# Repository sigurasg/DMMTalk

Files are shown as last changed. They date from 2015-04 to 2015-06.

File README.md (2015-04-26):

# DMMTalk

A battery-powered appendix to UNI-T 61E that speaks the settings and readings.

# TODO

* Add photodiode and amplifier for serial reception.
* Add button.
* Add volume control.
  * These two might take the form of a quadrature encoder with a button.
* Add headphone jack.
* Find a suitable SPI FLASH ROM.
  * Maybe [AT45DB081E
](http://www.adestotech.com/wp-content/uploads/DS-45DB081E_028.pdf)
  * Create a library component for same.
* Wire MSP430G2553 up.
  * RST/TEST go to RTS/CTS through resistors to allow BSL.
  * Need to find out how FT230 behaves without power, hopefully its outputs are
    3-state.
  * Even if it's tri-state, it'll conduct through the ESD protection diode, so
    this requires a switch to isolate the powered-down serial chip from
    the reset pin, as well as the TEST pin, to make sure in-circuit programming
    through the two-wire protocol works. Maybe something like
    http://www.onsemi.com/pub_link/Collateral/NL7WB66-D.PDF.
  * UCA0 or UCB0 drives the SPI bus.
  * One pin controls the analog power switch.
* Find suitable rail-to-rail op-amps.
  * Need 1.8V operating voltage at the bottom.
  * Need reasonable output current drive capability.
  * Maybe a bridge-drive headphone or speaker amp is better?

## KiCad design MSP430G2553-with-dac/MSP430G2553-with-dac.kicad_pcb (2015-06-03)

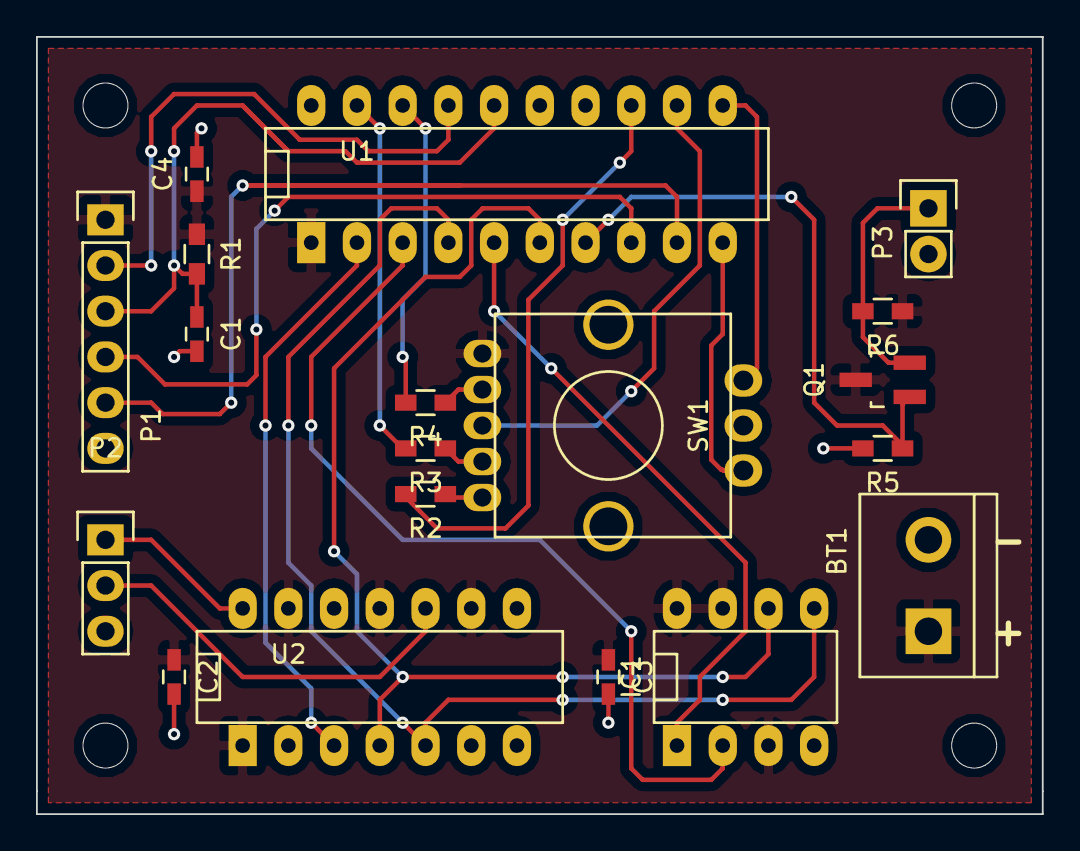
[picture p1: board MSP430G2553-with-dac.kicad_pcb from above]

Board: 2 copper layers, 55.9 x 43.2 mm, 19 parts (0 on the bottom side), 24 nets.

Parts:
BT1: Battery; bornier2
C1: 1n; C_0603_HandSoldering
C2, C3, C4: 100n; C_0603_HandSoldering
IC1: MX25L4006E; DIP-8__300_ELL
P1: DEBUG; Pin_Header_Straight_1x06
P2: OUT; Pin_Header_Straight_1x03
P3: PHOTODIODE; Pin_Header_Straight_1x02
Q1: 2N3906; SOT-23_Handsoldering
R1: 47K; R_0603_HandSoldering
R2, R3, R4: 220; R_0603_HandSoldering
R5, R6: 100K; R_0603_HandSoldering
SW1: PEL12T
U1: MSP430G2553IN20; DIP-20__300_ELL
U2: MCP4922-E/P; DIP-14__300_ELL

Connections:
/A_OUT: P2.1, U2.14
/BLED: R4.2, U1.18
/BUTTON: SW1.3, U1.12
/B_OUT: P2.2, U2.10
/DACCS#: U1.2, U2.3
/FLASHCS#: IC1.1, U1.5
/GLED: R3.2, U1.19
/PH_IN: Q1.1, R5.1, U1.7
/Q_A: SW1.8, U1.10
/Q_B: SW1.6, U1.11
/RLED: R2.2, U1.13
/RST#: C1.1, P1.3, R1.2, U1.16
/RXD: P1.4, U1.8
/SCK: IC1.6, U1.6, U2.4
/SDI: IC1.5, U1.4, U2.5
/SDO: IC1.2, U1.3
/TEST: P1.2, U1.17
/TXD: P1.5, U1.9
GND: BT1.2, C1.2, C2.2, C3.2, C4.2, IC1.4, P1.6, P2.3, P3.2, R5.2, SW1.7, U1.20, U2.8, U2.12
unnamed: P3.1, Q1.2, R6.2
unnamed: R2.1, SW1.1
unnamed: R3.1, SW1.2
unnamed: R4.1, SW1.4
VCC: BT1.1, C2.1, C3.1, C4.1, IC1.3, IC1.7, IC1.8, P1.1, Q1.3, R1.1, R6.1, SW1.5, U1.1, U2.1, U2.9, U2.11, U2.13

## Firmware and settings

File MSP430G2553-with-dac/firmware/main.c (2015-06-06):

/*
 * main.c
 *
 *  Created on: Jun 2, 2015
 *      Author: siggi
 */

#include <msp430.h>
#include <isr_compat.h>
#include <stdint.h>

#include "timer.h"

#define nullptr 0

// Hardware pins.
#define Q_A BIT2
#define Q_B BIT3
#define BUTTON BIT4

// The LEDs are inverted, pull down to turn LEDs on.
#define RLED BIT5
#define GLED BIT6
#define BLED BIT7
#define LEDMASK (RLED | GLED | BLED)

void InitClock() {
  // 16MHz DCO for main clock.
  BCSCTL1 = CALBC1_16MHZ;
  DCOCTL = CALDCO_16MHZ;
}

void InitTimer0() {
  // Set timer0 up for regular interrupts.
  TA0CTL = TASSEL_2 |  // Use SMCLK.
	   ID_0 |  // Divide by 1.
	   MC_2 |  // Continuous mode.
	   TAIE;  // Enable overflow interrupts.
}

void InitLEDPort() {
  P2SEL	&= ~LEDMASK;
  P2DIR |= LEDMASK;
  P2OUT |= LEDMASK;
}

void InitButtons() {
  // Button and quadrature switches are inputs.
  P2DIR &= ~(Q_A | Q_B | BUTTON);
  // Enable pulldown resistor for the button, and pullups
  // for the quadrature switches.
  P2REN |= (Q_A | Q_B | BUTTON);
  P2OUT &= ~BUTTON;
  P2OUT |= Q_A | Q_B;

  // Set up for interrupt on button low->high transition.
  // The button is N/O, connected to VCC with a pulldown.
  P2IES &= ~BUTTON;

  // And for quadrature changes.
  P2IES = (P2IES & ~(Q_A | Q_B)) | (P2IN & (Q_A | Q_B));

  // Enable the port interrupts.
  P2IE |= (Q_A | Q_B | BUTTON);
}

typedef struct RGB {
  uint8_t intens;
  uint8_t r, g, b;
} RGB;

RGB led = { 128, 127, 127, 127 };
uint8_t mode = 0;

static void PWMLEDs(struct Timer* t);
struct LEDTimerSchedule {
  // The current state 0-3.
  uint8_t state;
  // Mask of the LEDs that are on at any stage, ends in a zero mask.
  uint8_t masks[4];
  // The delay to the next state.
  uint32_t delays[4];
};
struct LEDTimerSchedule led_schedule;
struct LEDTimerSchedule next_led_schedule = {
    0,
    { LEDMASK, 0 },
    { 625Ul * 127, 625Ul * 128 }
};
struct Timer led_timer = { 0, PWMLEDs, nullptr };

static void SetLEDs(uint8_t mode, const RGB* led) {
  uint8_t values[3] = {0};
  uint8_t masks[3] = { RLED, GLED, BLED };
  uint8_t i, j, max;
  struct LEDTimerSchedule sch = {0};

  if (mode == 0 || mode == 1)
    values[0] = ((uint16_t)led->intens * led->r) >> 8;
  if (mode == 0 || mode == 2)
    values[1] = ((uint16_t)led->intens * led->g) >> 8;
  if (mode == 0 || mode == 3)
    values[2] = ((uint16_t)led->intens * led->b) >> 8;

  for (i = 0; i < 2; ++i) {
      for (j = i; j < 3; ++j) {
	  if (values[i] > values[j]) {
	      uint8_t tmp = values[i];
	      values[i] = values[j];
	      values[j] = tmp;
	      tmp = masks[i];
	      masks[i] = masks[j];
	      masks[j] = tmp;
	  }
      }
  }

  masks[1] |= masks[2];
  masks[0] |= masks[1];

  j = 0;
  max = 0;
  for (i = 0; i < 3; ++i) {
      if (values[i]) {
	  if (values[i] != max) {
	    sch.delays[j] = 625ul * (values[i] - max);
	    sch.masks[j++] = masks[i];
	    max = values[i];
	  }
      }
  }
  sch.delays[j] = 625ul * (256ul - max);

  next_led_schedule = sch;
}

static void PWMLEDs(struct Timer* t) {
  uint8_t mask = led_schedule.masks[led_schedule.state];
  P2OUT = (P2OUT & ~LEDMASK) | (LEDMASK & ~mask);
  t->ticks += led_schedule.delays[led_schedule.state++];
  Schedule(t);

  if (mask == 0) {
      led_schedule = next_led_schedule;
      led_schedule.state = 0;
  }
}

ISR(TIMER0_A1, TA0_INT) {
  if (TAIV == TA0IV_TAIFG)
    OnTimerOverflow();
}

ISR(TIMER0_A0, TA0CCR0_INT) {
  OnTimerInterrupt();
}

void DebounceButton(struct Timer* timer) {
  // Re-enable the button interrupt.
  P2IE |= BUTTON;
  if ((P2IN & BUTTON) == 0)
    return;

  ++mode;
  if (mode == 4)
    mode = 0;

  SetLEDs(mode, &led);
}

struct Timer debounce_timer = { 0, DebounceButton };

void OnButtonPress() {
  // Disable the button interrupt.
  P2IE &= ~BUTTON;
  // 10ms de-bounce.
  debounce_timer.ticks = GetTicks() + 160000;
  Schedule(&debounce_timer);
}

static const int8_t dir[16] = {
    0,   // 00 00
    -1,  // 00 01
    1,   // 00 10
    0,   // 00 11
    1,   // 01 00
    0,   // 01 01
    0,   // 01 10
    -1,  // 01 11
    -1,  // 10 00
    0,   // 10 01
    0,   // 10 10
    1,   // 10 11
    0,   // 11 00
    1,   // 11 01
    -1,  // 11 10
    0,   // 11 11
};

uint32_t pos = 0;
uint32_t neg = 0;
uint32_t zero = 0;

static void Adjust(int adj, uint8_t* value) {
  if (adj == -1 && *value == 0)
    return;
  if (adj == 1 && *value == 255)
    return;
  *value += adj;
}

static void OnEncoderInterrupt(uint8_t mask) {
  static uint8_t last_q = 0;
  uint8_t q = P2IN & (Q_A | Q_B);

  // Set up for the next quadrature change.
  P2IES = (P2IES & ~(Q_A | Q_B)) | q;

  int adj = dir[last_q | q];
  switch (adj) {
    case -1:
      ++neg;
      break;
    case 1:
      ++pos;
      break;
    case 0:
      ++zero;
      break;
  }

  last_q = q >> 2;

  if (adj == 0)
    return;

  switch (mode) {
    case 0:
      Adjust(adj, &led.intens);
      break;
    case 1:
      Adjust(adj, &led.r);
      break;
    case 2:
      Adjust(adj, &led.g);
      break;
    case 3:
      Adjust(adj, &led.b);
      break;
  }

  SetLEDs(mode, &led);
}

ISR(PORT2, PORT2INT) {
  // Acknowledge the interrupt.
  uint8_t ports = P2IFG;
  P2IFG ^= ports;

  if (ports & BUTTON)
    OnButtonPress();
  else if (ports & (Q_A | Q_B))
    OnEncoderInterrupt(ports & (Q_A | Q_B));
}

int main() {
  // Disable the watchdog.
  WDTCTL = WDTPW | WDTHOLD;

  InitClock();
  InitTimer0();
  InitLEDPort();
  InitButtons();

  Schedule(&led_timer);

  // Enable interrupts and go to sleep.
  __enable_interrupt();

  // LPM1 is just right, as it keeps the DCO going.
  LPM1;

  return 0;
}

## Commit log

2015-04-20 Start DMMTalk.
    [DMMTalk.sch]
2015-04-20 Add 47pF caps on USB, add a TODO list.
    [DMMTalk.sch]
2015-04-25 Migrate to ToT KiCAD.
    [DMMTalk.sch]
2015-04-26 Work on a few things.
    [DMMTalk.sch]
2015-05-07 Make a start on MSP430G2553 with DAC et al.
    [DMMTalk.sch, MSP430G2553-with-dac.kicad_pcb, MSP430G2553-with-dac.sch]
2015-05-10 430/DAC board laid out. Probably badly
    [MSP430G2553-with-dac.dsn]
2015-05-10 Ready for manufacture.
    [MSP430G2553-with-dac.kicad_pcb]
2015-06-03 Cosmetic changes + start firmware.
    [MSP430G2553-with-dac.kicad_pcb, MSP430G2553-with-dac.sch]
2015-06-05 Make a start on a generic time service.
    [MSP430G2553-with-dac.sch]
2015-06-05 WIP: Wire LED PWM to timer.
2015-06-06 Fix many things; interrupt handling, timer chaining, button interrupt edge, quadrature edge setup, etc.
    [main.c]
2015-06-06 Signed time to survive rollover. Fix quadrature mask setup. Eliminate flicker on LED setup.
    [main.c]
2015-06-06 Moar time rollover fixing.
    [main.c]
2015-06-06 Fix de-bouncing and now really fix rollover - really.
    [main.c]
2015-06-06 Rename some functions, move timer code to a separate file.
2015-06-06 Get rid of 1us glitch on each LED PWM period. Cosmetic cleanup.
    [main.c]
